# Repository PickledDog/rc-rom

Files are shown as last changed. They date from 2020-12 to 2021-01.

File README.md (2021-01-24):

# rc-rom
 ROM card for RC2014
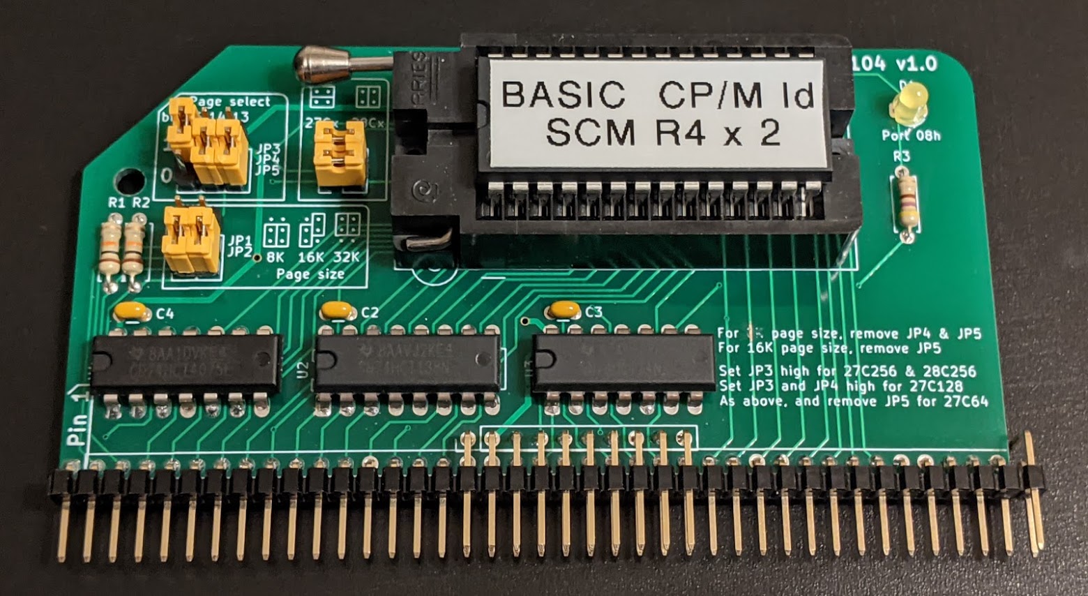
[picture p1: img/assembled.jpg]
Assembled PD104

(version 1.0 shown, current version 1.1 has a second LED for paging status)

## Overview
This RC2014-compatible board provides ROM from an EPROM or EEPROM, with 8k/16k/32k granularity. The ROM can be paged out and replaced by RAM, when combined with a compatible RAM card. A user-controllable LED is also provided.

## ROM
This board provides ROM to a RC2014 system. It does not provide RAM, but can interact with a compatible RAM card. The [official RC2014 64K RAM](https://rc2014.co.uk/modules/64k-ram/) card is supported, as is the [PD101 board](https://github.com/PickledDog/rc-z80ram), which it was designed in tandem with.

## Paging
Paging (the ability to replace the ROM with RAM) is implemented using the *PAGE* signal in the RC2014 Enhanced Bus. This is the only Enhanced Bus signal required - if you're using a Standard Bus backplane (or don't intend to install a two-row header), a wire can be used to link the page signals between this board and the RAM (the pin in question is #4 of the 10 Enhanced pins).

If the *PAGE* signal cannot be connected, any RAM in the system will need to be configured to not appear in the lower memory addresses used by the ROM - consult the documentation of the RAM board. PD101 *cannot* selectively disable memory like this, and requires the PAGE signal in order to work with this board. Alternatively, [PD106](https://github.com/PickledDog/rc-ramrom) can be built instead of this board, since it has RAM built-in and doesn't require the Enhanced bus.

## Software compatibility
The board presents two I/O devices to the system - the LED at base port 0x08, and the ROM paging at 0x38. The LED appears at the same address as the LED of the [SC114 Motherboard](https://smallcomputercentral.wordpress.com/sc114-documentation/), and the ROM control address is common to most Z80 retrocomputers (the official RC2014 RAM/ROM cards included). As such, this board is compatible with most SC114 software, as well as Grant Searle's CP/M loader. LED is active low (lights by default) - writing a **1** to 0x08 turns it off. Writing a **1** to 0x38 disables the ROM.

## Chip support
The board supports 27C64, 27C128, 27C256, and 27C512 EPROMs, as well as 28C64 and 28C256 EEPROMs. Other chips with similar pinouts will *probably* work, but are untested. 150ns parts (like most 28C256s) are running at the edge of their specification in a standard 7.3Mhz system, and may require lowering the CPU clock. The [27C256](https://www.mouser.com/ProductDetail/AT27C256R-70PU/), [27C512](https://www.mouser.com/ProductDetail/AT27C512R-70PU/), and [28C256](https://www.mouser.com/ProductDetail/AT28C256-15PU/) can be purchased new.

## Firmware
Most (if not all) [RC2014 ROM images](https://github.com/RC2014Z80/RC2014/tree/master/ROMs) can be used unmodified (selecting the right images for your serial board, of course). Stephen C Cousins' excellent [Small Computer Monitor](https://smallcomputercentral.wordpress.com/small-computer-monitor/) can be used as well - all of the R* configurations are supported. You will need an EPROM programmer (for example, a [TL866](https://www.ebay.com/sch/i.html?_nkw=tl866ii+plus)) to load the ROM images onto a chip.

## Jumper settings
Refer to the front of the board for detailed jumper setting instructions.

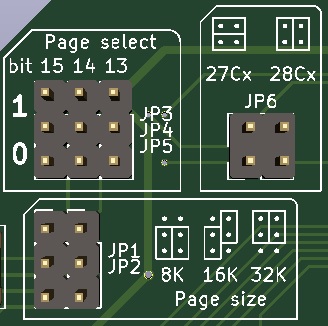
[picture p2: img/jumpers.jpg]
Jumpers
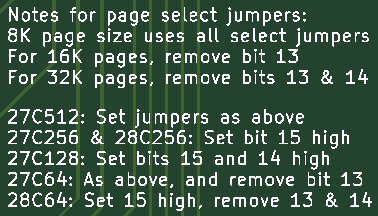
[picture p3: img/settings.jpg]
Settings
 

## Part selection
Bill Of Materials and part references are below. In order to make the 50-pin RC2014 Enhanced bus connector, you'll need to take a 2x40-pin right-angle header and pull out most of the pins from the top row (needle-nose pliers work well). I recommend using gold-plated header for this - I use these ones from [Pololu](https://www.pololu.com/product/2668) or [Sparkfun](https://www.sparkfun.com/products/12792). The jumper headers can be snapped from regular (or double-row) breakaway header, for which eBay is substantially cheaper; the Mouser listings are provided for convenience.

The specified parts are just the ones I used, and can be substituted as needed - Mouser links provided for convenience and reference. A ZIF socket can be used for the EPROM - these are best [sourced from eBay](https://www.ebay.com/sch/i.html?_nkw=28+pin+zif+socket).

| Reference | Value | Qty | Mouser link |
| --- | ----- | --- | --- |
| C1-C4 | 100nF ceramic | 4 | [KEMET C315C104M5U5TA](https://www.mouser.com/ProductDetail/C315C104M5U5TA7303) |
| D1 | 3mm yellow LED | 1 | [Lite-On LTL-4251N](https://www.mouser.com/ProductDetail/LTL-4251N) |
| D2 | 3mm green LED | 1 | [Lite-On LTL-4231N](https://www.mouser.com/ProductDetail/LTL-4231N) |
| J1/2 | 2x40 right-angle header | 1 | [3M 2380-5121TG](https://www.mouser.com/ProductDetail/2380-5121TG) |
| JP1/2 | 2x3 header | 1 | [Amphenol 10129381-906002BLF](https://www.mouser.com/ProductDetail/10129381-906002BLF) |
| JP3/4/5 | 3x3 header | 1 | [Samtec TSW-103-07-L-T](https://www.mouser.com/ProductDetail/TSW-103-07-L-T) |
| JP6 | 2x2 header | 1 | [Amphenol 10129381-904002BLF](https://www.mouser.com/ProductDetail/10129381-904002BLF) |
| | jumpers | 7 | [Harwin M7583-46](https://www.mouser.com/ProductDetail/M7583-46)
| R1, R2 | 10kΩ resistor | 2 | [Yageo CFR-25JT-52-10K](https://www.mouser.com/ProductDetail/CFR-25JT-52-10K) |
| R3, R4 | 470Ω resistor | 2 | [Yageo CFR-25JT-52-470R](https://www.mouser.com/ProductDetail/CFR-25JT-52-470R) |
| U1 | EPROM | 1 | (see above for EPROM choices) |
| | socket | 1 | [Amphenol DILB28P-223TLF](https://www.mouser.com/ProductDetail/DILB28P-223TLF), or above ZIF |
| U2 | 74HCT138 | 1 | [TI SN74HCT138N](https://www.mouser.com/ProductDetail/SN74HCT138N) |
| U3 | 74HCT74 | 1 | [TI SN74HCT74N](https://www.mouser.com/ProductDetail/SN74HCT74N) |
| U4 | 74HCT4075 | 1 | [TI CD74HCT4075E](https://www.mouser.com/ProductDetail/CD74HCT4075E) |

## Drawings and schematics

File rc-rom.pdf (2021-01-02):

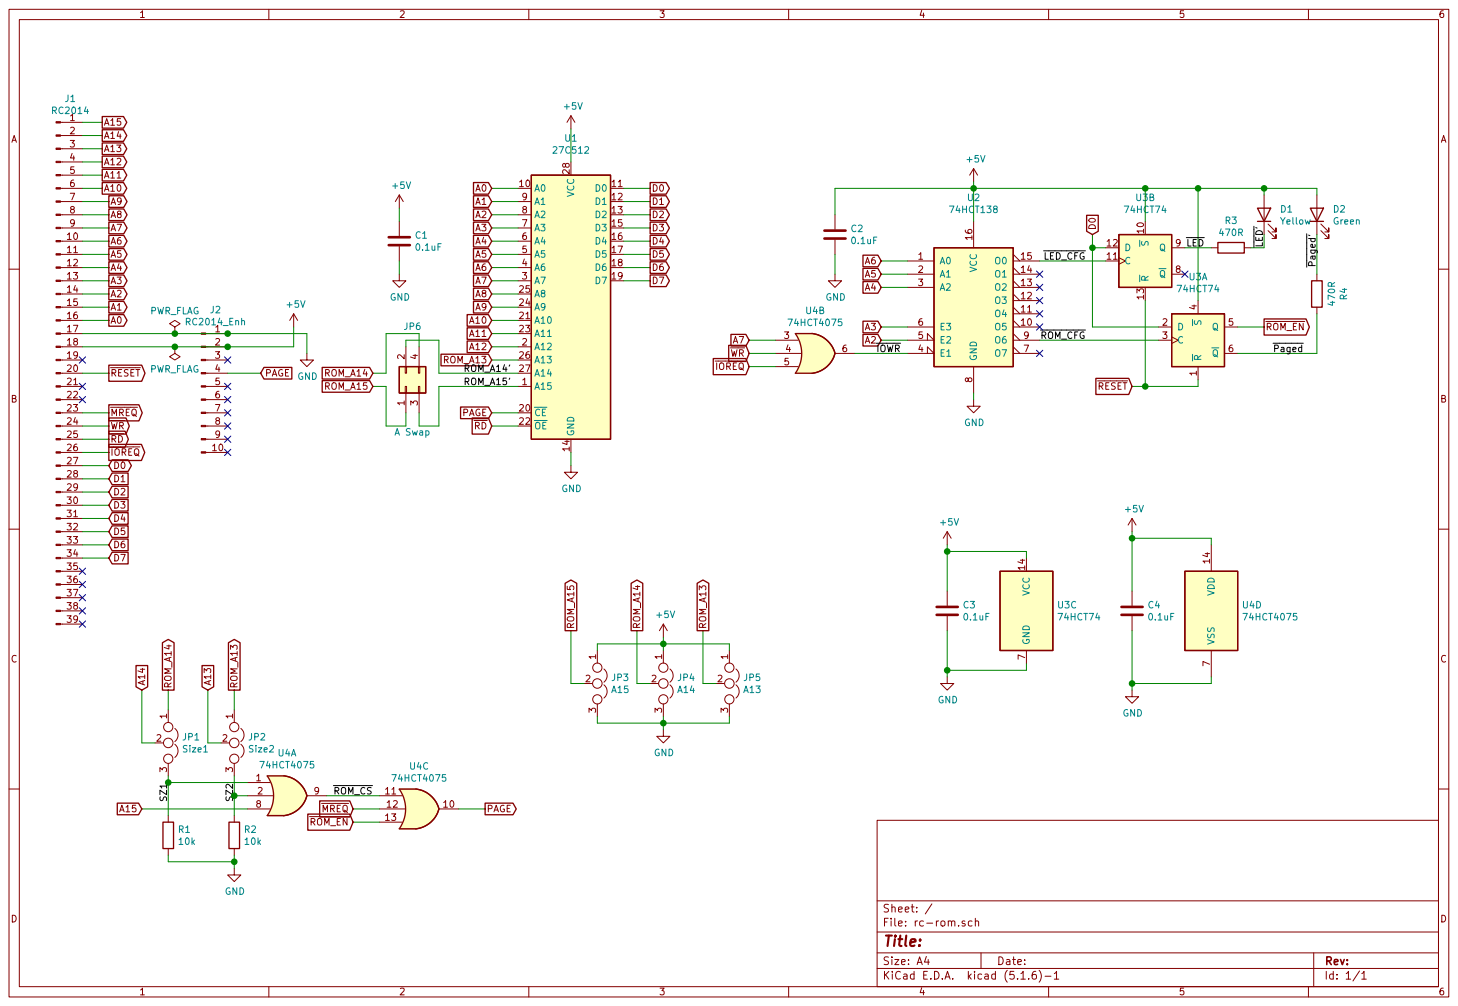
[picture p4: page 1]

Id: 1/1 Title: File: rc-rom.sch Sheet: / GND

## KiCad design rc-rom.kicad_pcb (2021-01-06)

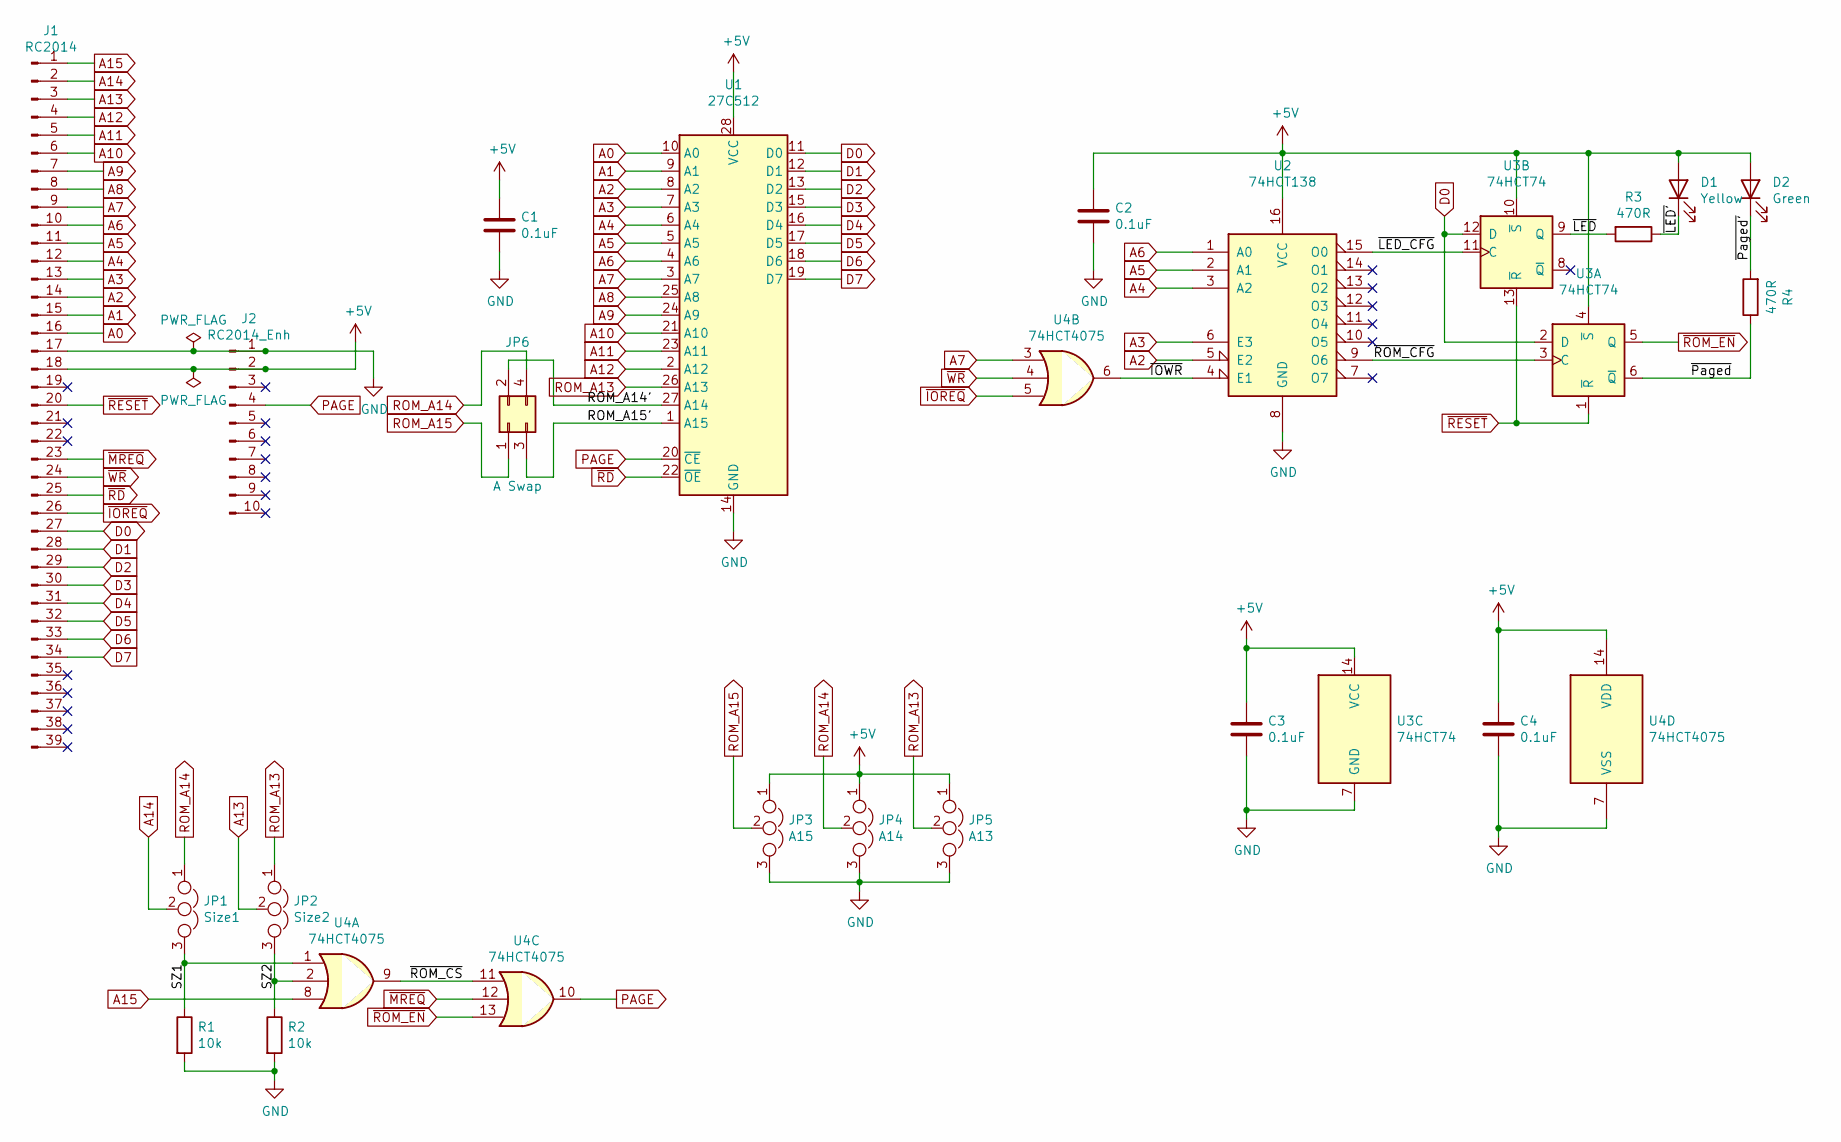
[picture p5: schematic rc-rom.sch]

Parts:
C1, C2, C3, C4: 0.1uF; C_Disc_D3.0mm_W1.6mm_P2.50mm
D1: Yellow; LED_D3.0mm
D2: Green; LED_D3.0mm
J1: RC2014; PinHeader_1x39_P2.54mm_Vertical
J2: RC2014_Enh; PinHeader_1x10_P2.54mm_Vertical
JP1: Size1; PinHeader_1x03_P2.54mm_Vertical
JP2: Size2; PinHeader_1x03_P2.54mm_Vertical
JP3: A15; PinHeader_1x03_P2.54mm_Vertical
JP4: A14; PinHeader_1x03_P2.54mm_Vertical
JP5: A13; PinHeader_1x03_P2.54mm_Vertical
JP6: A Swap; PinHeader_2x02_P2.54mm_Vertical
R1, R2: 10k; R_Axial_DIN0207_L6.3mm_D2.5mm_P7.62mm_Horizontal
R3, R4: 470R; R_Axial_DIN0207_L6.3mm_D2.5mm_P7.62mm_Horizontal
U1: 27C512; DIP_Socket-28_W11.9_W12.7_W15.24_W17.78_W18.5_3M_228-1277-0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
U2: 74HCT138; DIP-16_W7.62mm_LongPads
U3: 74HCT74; DIP-14_W7.62mm_LongPads
U4: 74HCT4075; DIP-14_W7.62mm_LongPads

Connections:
+5V: C1.1, C2.1, C3.1, C4.1, D1.2 (A), D2.2 (A), J1.18, J2.2, JP3.1, JP4.1, JP5.1, U1.28 (VCC), U2.16 (VCC), U3.4 (~S), U3.10 (~S), U3.14 (VCC), U4.14 (VDD)
/ROM_A14': JP6.2, U1.27 (A14)
/ROM_A15': JP6.3, U1.1 (A15)
/SZ1: JP1.3, R1.1, U4.1
/SZ2: JP2.3, R2.1, U4.2
/~IOWR: U2.4 (E1), U4.6
/~LED: R3.2, U3.9 (Q)
/~LED': D1.1 (K), R3.1
/~LED_CFG: U2.15 (O0), U3.11 (C)
/~Paged: R4.1, U3.6 (~Q)
/~Paged': D2.1 (K), R4.2
/~ROM_CFG: U2.9 (O6), U3.3 (C)
/~ROM_CS: U4.9, U4.11
A0: J1.16, U1.10 (A0)
A1: J1.15, U1.9 (A1)
A2: J1.14, U1.8 (A2), U2.5 (E2)
A3: J1.13, U1.7 (A3), U2.6 (E3)
A4: J1.12, U1.6 (A4), U2.3 (A2)
A5: J1.11, U1.5 (A5), U2.2 (A1)
A6: J1.10, U1.4 (A6), U2.1 (A0)
A7: J1.9, U1.3 (A7), U4.3
A8: J1.8, U1.25 (A8)
A9: J1.7, U1.24 (A9)
A10: J1.6, U1.21 (A10)
A11: J1.5, U1.23 (A11)
A12: J1.4, U1.2 (A12)
A13: J1.3, JP2.2
A14: J1.2, JP1.2
A15: J1.1, U4.8
D0: J1.27, U1.11 (D0), U3.2 (D), U3.12 (D)
D1: J1.28, U1.12 (D1)
D2: J1.29, U1.13 (D2)
D3: J1.30, U1.15 (D3)
D4: J1.31, U1.16 (D4)
D5: J1.32, U1.17 (D5)
D6: J1.33, U1.18 (D6)
D7: J1.34, U1.19 (D7)
GND: C1.2, C2.2, C3.2, C4.2, J1.17, J2.1, JP3.3, JP4.3, JP5.3, R1.2, R2.2, U1.14 (GND), U2.8 (GND), U3.7 (GND), U4.7 (VSS)
PAGE: J2.4, U1.20 (~CE), U4.10
ROM_A13: JP2.1, JP5.2, U1.26 (A13)
ROM_A14: JP1.1, JP4.2, JP6.4
ROM_A15: JP3.2, JP6.1
~IOREQ: J1.26, U4.5
~MREQ: J1.23, U4.12
~RD: J1.25, U1.22 (~OE)
~RESET: J1.20, U3.1 (~R), U3.13 (~R)
~ROM_EN: U3.5 (Q), U4.13
~WR: J1.24, U4.4

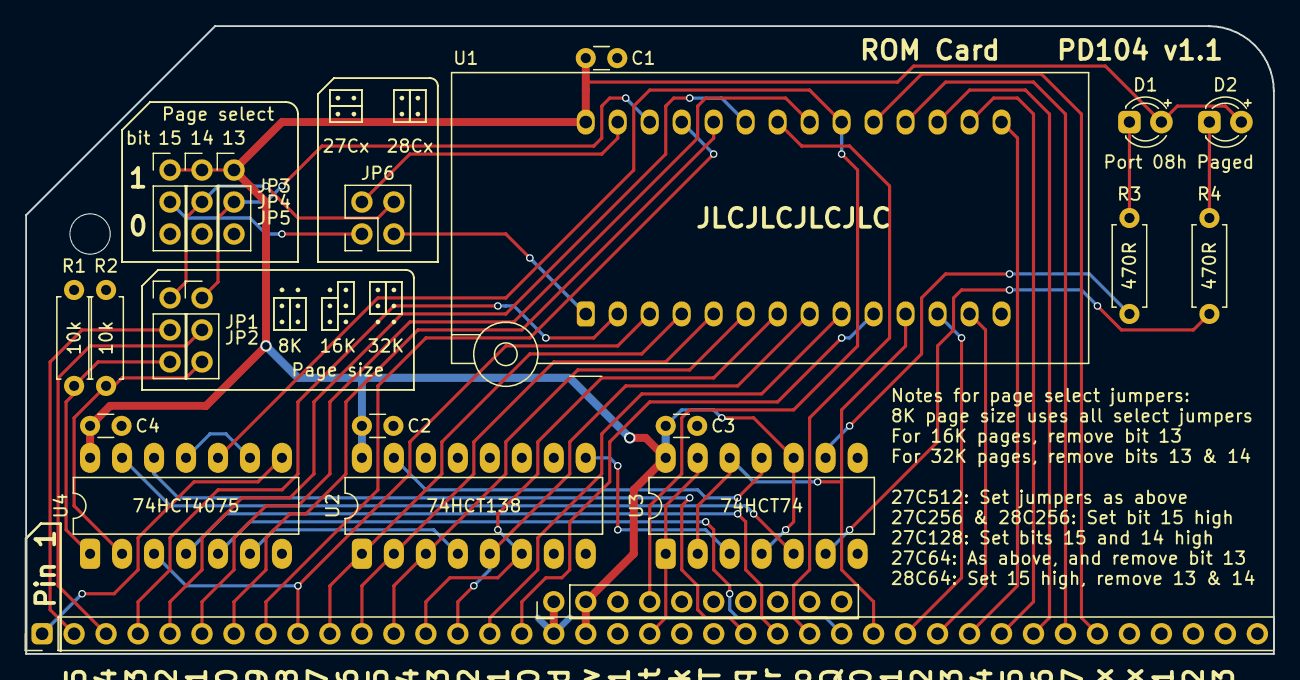
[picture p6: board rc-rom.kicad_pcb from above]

Board: 2 copper layers, 99.1 x 49.9 mm, 22 parts (0 on the bottom side), 48 nets.

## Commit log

2020-11-27 Initial commit of rc-rom
    Initial commit of rc-rom/PD104
    [rc-rom-B_Cu.gbr, rc-rom-B_Mask.gbr, rc-rom-B_SilkS.gbr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]
2020-12-02 Added silkscreen jumper diagrams, tweaked net labels
    Added reference diagrams for jumpers on the silkscreen, tweaked net labels
    [rc-rom-B_Cu.gbr, rc-rom-B_Mask.gbr, rc-rom-B_SilkS.gbr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]
2020-12-09 Fix silk instructions
    Whoops the jumper instructions on the silk were wrong
    [rc-rom-B_Cu.gbr, rc-rom-B_Mask.gbr, rc-rom-B_SilkS.gbr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]
2020-12-27 Added README, tidied up schematic and board
    [rc-rom-B_Cu.gbr, rc-rom-B_Mask.gbr, rc-rom-B_SilkS.gbr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]
2020-12-30 Add board photos
2021-01-02 Moved to version 1.1, added LED for paging status
    [rc-rom-B_Cu.gbr, rc-rom-B_Mask.gbr, rc-rom-B_SilkS.gbr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]
2021-01-06 Update silkscreen
    [rc-rom-B_Cu.gbr, rc-rom-B_Mask.gbr, rc-rom-B_SilkS.gbr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]
